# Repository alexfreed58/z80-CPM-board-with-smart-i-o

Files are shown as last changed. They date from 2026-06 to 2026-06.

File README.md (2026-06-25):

# z80-CPM-board-with-smart-I/O
<p>This is yet another retro computer running CPM on an actual Z80 CPU with a twist. Instead of using a traditional UART for communications, it uses a RPi pico module that is no bigger and no more expensive than a UART. But it can do a whole lot more. On this board it also generates the CPU clock that can be set to any desired frequency. If you have a 20 MHz Z80, use 20 MHz.</p>
<p>
There is also a provision to add an ESP32 module that allows connecting to the board via WiFi (telnet server) or BlueTooth. Of course you need to load a simple program onto the ESP32 from the ESP32 examples with some  modifications. Arduino works well.</p>
<p>
I use an SD card for disk emulation. I made a lot of design choices to be somewhat compatible with John Winans' z80-retro computer: "disk" geometry and memory management in particular. However my SD interface is quite different. Instead of bit-banging SPI, I use a couple of TTL (or CMOS) chips. The heart of the interface is a 74(LS/HC)299 universal shift register and some glue logic. I have decided to use several off-the-shelf chips rather than  a single CPLD because if anybody decides to use my design, it will be a lot easier if you don't have much experience with programmable logic. As a result the SPI interface runs at the full CPU clock speed  and to transmit and receive a byte via SPI you only need to write one byte to an i/o port and read a byte back.</p> 
<p>
The board design is done with the (fantastic!) open source Kicad. Likely much less than perfect as it is my first Licad project ever. I used mostly Altium Designer for professional work, but since Kicad is free, anyone can modify and improve the board.</p>

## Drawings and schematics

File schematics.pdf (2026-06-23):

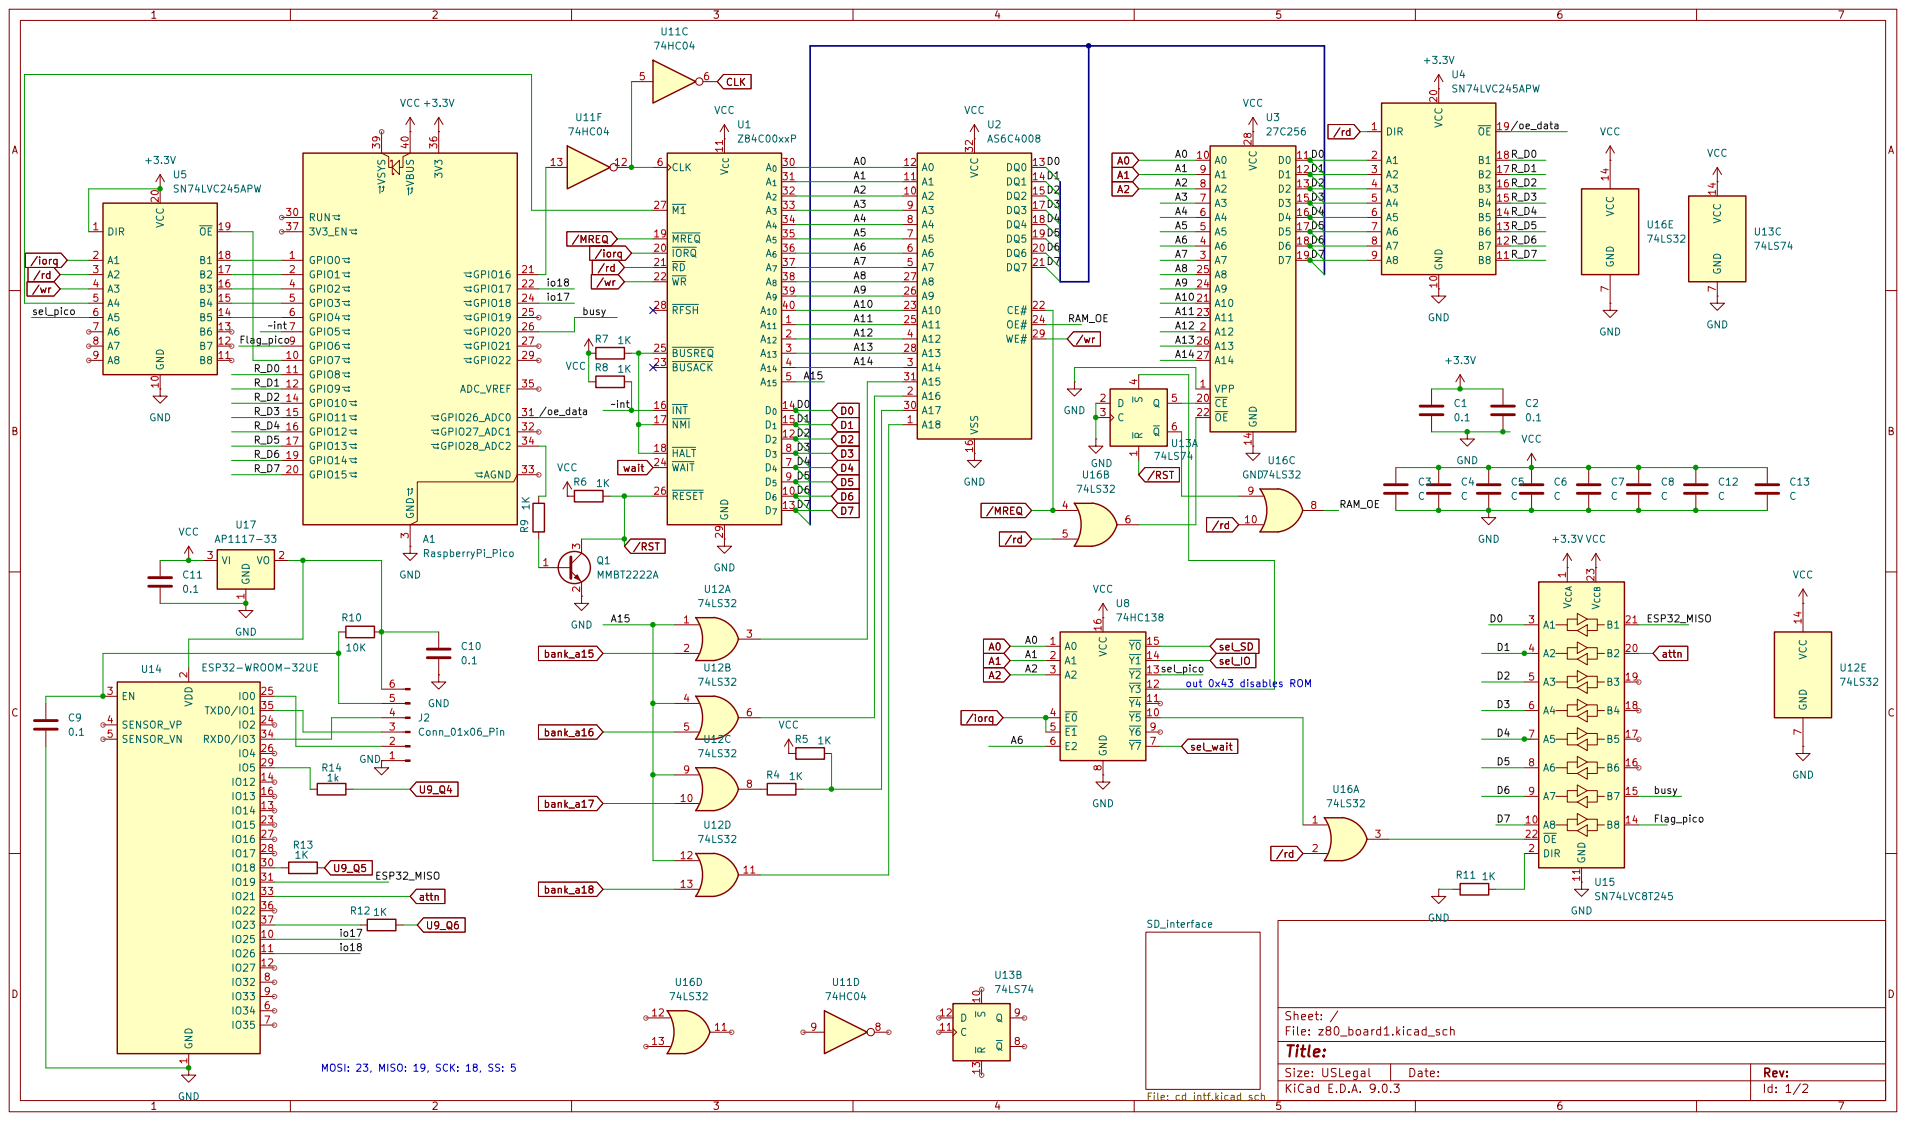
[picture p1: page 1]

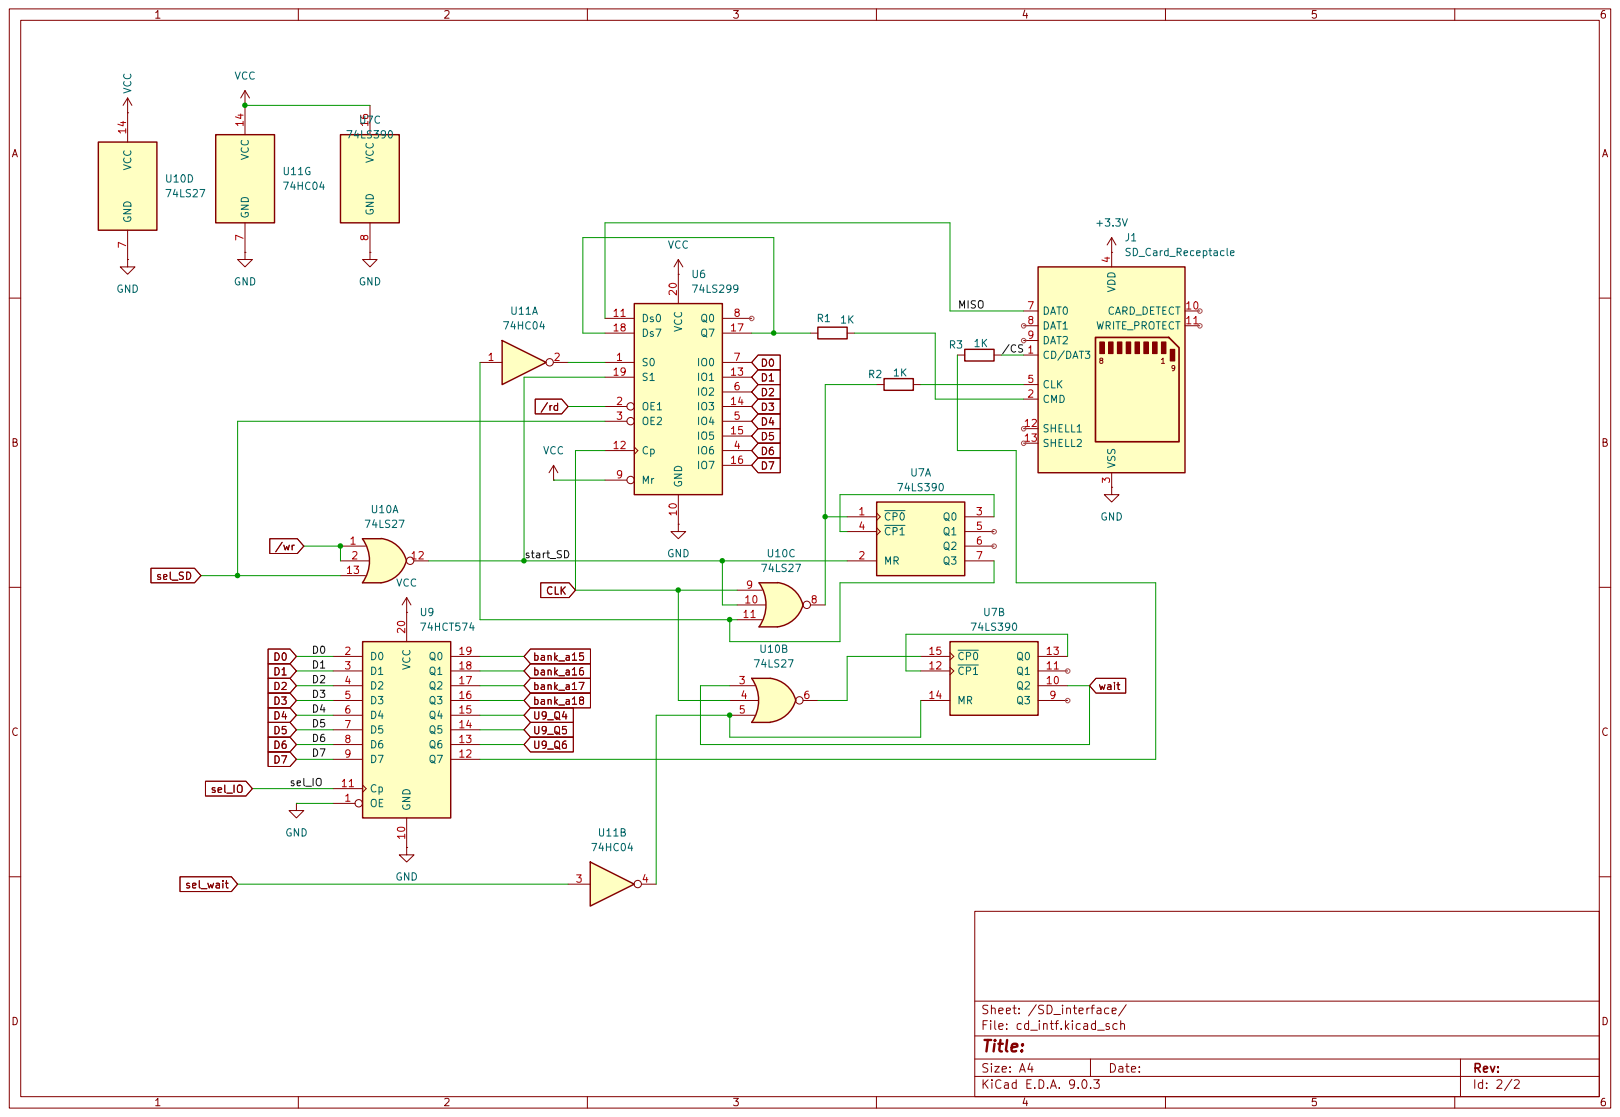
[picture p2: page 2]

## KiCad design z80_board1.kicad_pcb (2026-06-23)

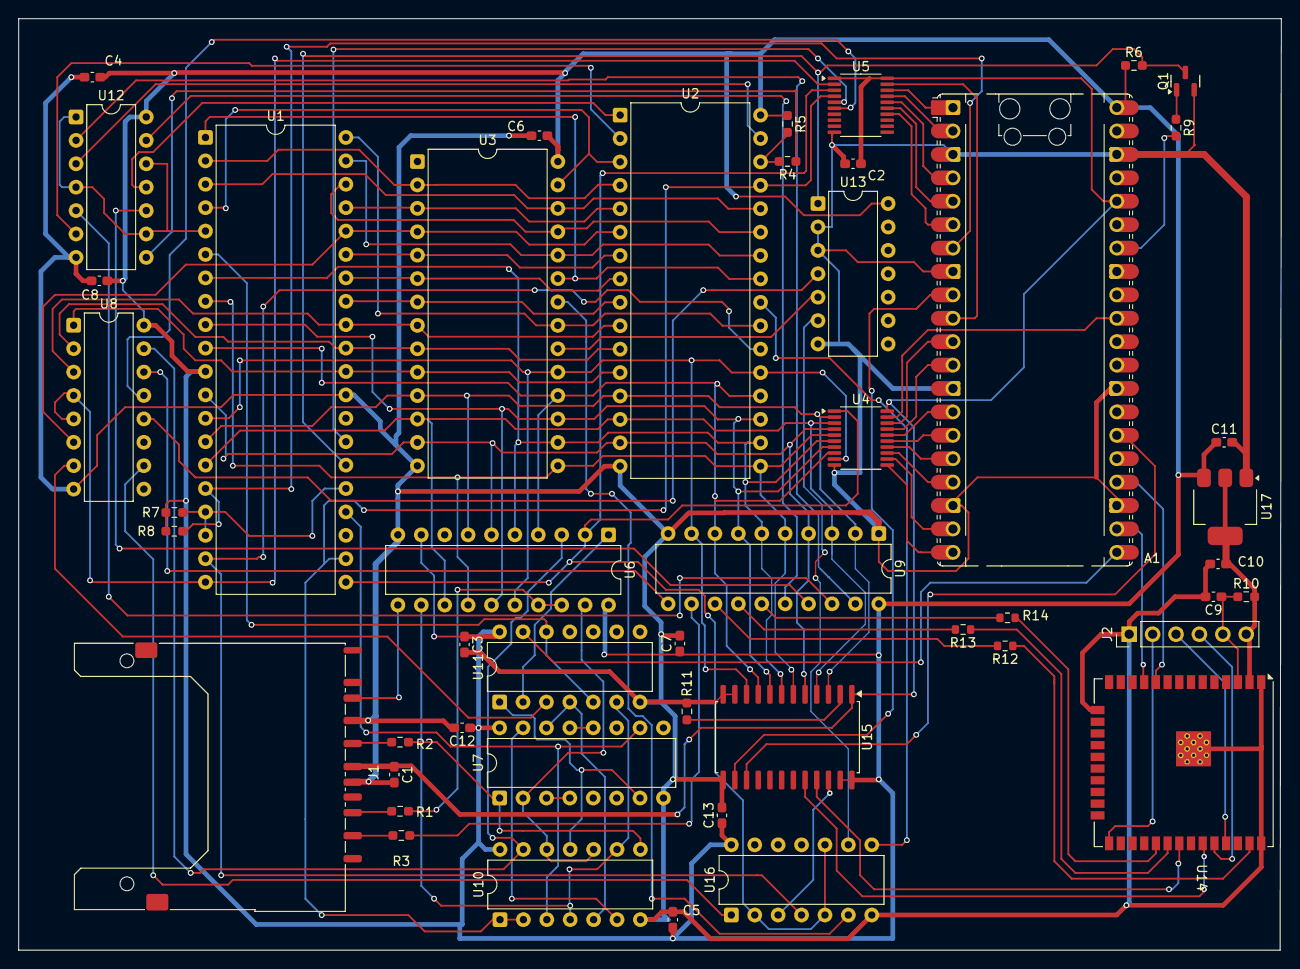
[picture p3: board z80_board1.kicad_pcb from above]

Board: 2 copper layers, 137.0 x 101.1 mm, 48 parts (0 on the bottom side), 108 nets.

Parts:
A1: RaspberryPi_Pico; RaspberryPi_Pico_Common_Unspecified
C1, C2, C9, C10, C11: 0.1; C_0603_1608Metric_Pad1.08x0.95mm_HandSolder
C3, C4, C5, C6, C7, C8, C12, C13: C; C_0603_1608Metric_Pad1.08x0.95mm_HandSolder
J1: SD_Card_Receptacle; SD_Kyocera_145638009511859+
J2: Conn_01x06_Pin; PinHeader_1x06_P2.54mm_Vertical
Q1: MMBT2222A; SOT-23
R1, R2, R3, R4, R5, R6, R7, R8, R9, R11: 1K; R_0603_1608Metric_Pad0.98x0.95mm_HandSolder
R10: 10K; R_0603_1608Metric_Pad0.98x0.95mm_HandSolder
R12, R13: 1K; R_0603_1608Metric
R14: 1k; R_0603_1608Metric
U1: Z84C00xxP; DIP-40_W15.24mm
U2: AS6C4008; DIP-32_W15.24mm
U3: 27C256; DIP-28_W15.24mm
U4, U5: SN74LVC245APW; TSSOP-20_4.4x6.5mm_P0.65mm
U6: 74LS299; DIP-20_W7.62mm
U7: 74LS390; DIP-16_W7.62mm
U8: 74HC138; DIP-16_W7.62mm
U9: 74HCT574; DIP-20_W7.62mm
U10: 74LS27; DIP-14_W7.62mm
U11: 74HC04; DIP-14_W7.62mm
U12, U16: 74LS32; DIP-14_W7.62mm
U13: 74LS74; DIP-14_W7.62mm
U14: ESP32-WROOM-32UE
U15: SN74LVC8T245; SOIC-24W_7.5x15.4mm_P1.27mm
U17: AP1117-33; SOT-223-3_TabPin2

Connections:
+3.3V: A1.36 (3V3), C1.1, C2.1, J1.4 (VDD), U4.20 (VCC), U5.1 (DIR), U5.20 (VCC), U15.1 (V_{CCA})
/A3: U1.33 (A_{3}), U2.9 (A3), U3.7 (A3)
/A4: U1.34 (A_{4}), U2.8 (A4), U3.6 (A4)
/A5: U1.35 (A_{5}), U2.7 (A5), U3.5 (A5)
/A6: U1.36 (A_{6}), U2.6 (A6), U3.4 (A6), U8.6 (E2)
/A7: U1.37 (A_{7}), U2.5 (A7), U3.3 (A7)
/A8: U1.38 (A_{8}), U2.27 (A8), U3.25 (A8)
/A9: U1.39 (A_{9}), U2.26 (A9), U3.24 (A9)
/A10: U1.40 (A_{10}), U2.23 (A10), U3.21 (A10)
/A11: U1.1 (A_{11}), U2.25 (A11), U3.23 (A11)
/A12: U1.2 (A_{12}), U2.4 (A12), U3.2 (A12)
/A13: U1.3 (A_{13}), U2.28 (A13), U3.26 (A13)
/A14: U1.4 (A_{14}), U2.3 (A14), U3.27 (A14)
/A15: U1.5 (A_{15}), U12.1, U12.4, U12.9, U12.12
/ESP32_MISO: U14.31 (IO19), U15.21 (B1)
/Flag_pico: A1.9 (GPIO6), U15.14 (B8)
/RAM_OE: U2.24 (OE#), U16.8
/R_D0: A1.11 (GPIO8), U4.18 (B1)
/R_D1: A1.12 (GPIO9), U4.17 (B2)
/R_D2: A1.14 (GPIO10), U4.16 (B3)
/R_D3: A1.15 (GPIO11), U4.15 (B4)
/R_D4: A1.16 (GPIO12), U4.14 (B5)
/R_D5: A1.17 (GPIO13), U4.13 (B6)
/R_D6: A1.19 (GPIO14), U4.12 (B7)
/R_D7: A1.20 (GPIO15), U4.11 (B8)
/SD_interface/MISO: J1.7 (DAT0), U6.11 (Ds0)
/SD_interface/start_SD: U6.19 (S1), U7.2 (MR), U10.10, U10.12
/SD_interface//CS: J1.1 (CD/DAT3), R3.1
/busy: A1.26 (GPIO20), U15.15 (B7)
/io17: A1.24 (GPIO18), U14.10 (IO25)
/io18: A1.22 (GPIO17), U14.11 (IO26)
/sel_pico: U5.6 (A5), U8.13 (~Y2)
//oe_data: A1.31 (GPIO26_ADC0), U4.19 (~OE)
/~int: A1.7 (GPIO5), R8.2, U1.16 (~INT)
A0: U1.30 (A_{0}), U2.12 (A0), U3.10 (A0), U8.1 (A0)
A1: U1.31 (A_{1}), U2.11 (A1), U3.9 (A1), U8.2 (A1)
A2: U1.32 (A_{2}), U2.10 (A2), U3.8 (A2), U8.3 (A2)
CLK: U6.12 (Cp), U10.4, U10.9, U11.6
D0: U1.14 (D_{0}), U2.13 (DQ0), U3.11 (D0), U4.2 (A1), U6.7 (IO0), U9.2 (D0), U15.3 (A1)
D1: U1.15 (D_{1}), U2.14 (DQ1), U3.12 (D1), U4.3 (A2), U6.13 (IO1), U9.3 (D1), U15.4 (A2)
D2: U1.12 (D_{2}), U2.15 (DQ2), U3.13 (D2), U4.4 (A3), U6.6 (IO2), U9.4 (D2), U15.5 (A3)
D3: U1.8 (D_{3}), U2.17 (DQ3), U3.15 (D3), U4.5 (A4), U6.14 (IO3), U9.5 (D3), U15.6 (A4)
D4: U1.7 (D_{4}), U2.18 (DQ4), U3.16 (D4), U4.6 (A5), U6.5 (IO4), U9.6 (D4), U15.7 (A5)
D5: U1.9 (D_{5}), U2.19 (DQ5), U3.17 (D5), U4.7 (A6), U6.15 (IO5), U9.7 (D5), U15.8 (A6)
D6: U1.10 (D_{6}), U2.20 (DQ6), U3.18 (D6), U4.8 (A7), U6.4 (IO6), U9.8 (D6), U15.9 (A7)
D7: U1.13 (D_{7}), U2.21 (DQ7), U3.19 (D7), U4.9 (A8), U6.16 (IO7), U9.9 (D7), U15.10 (A8)
GND: A1.3 (GND), A1.8 (GND), A1.13 (GND), A1.18 (GND), A1.23 (GND), A1.28 (GND), A1.38 (GND), C1.2, C2.2, C3.2, C4.2, C5.2, C6.2, C7.2, C8.2, C9.2, C10.2, C11.2, C12.2, C13.2, J1.3 (VSS), J1.6 (VSS), J2.1, Q1.2 (E), R11.1, U1.29 (GND), U2.16 (VSS), U3.1 (VPP), U3.14 (GND), U4.10 (GND), U5.10 (GND), U6.10 (GND), U7.8 (GND), U8.8 (GND), U9.1 (OE), U9.10 (GND), U10.7 (GND), U11.7 (GND), U12.7 (GND), U13.2 (D), U13.3 (C), U13.7 (GND), U14.1 (GND), U14.15 (GND), U14.38 (GND), U14.39 (GND), U15.11 (GND), U15.12 (GND), U15.13 (GND), U16.7 (GND), U17.1 (GND)
unnamed: A1.1 (GPIO0), U5.18 (B1)
unnamed: A1.2 (GPIO1), U5.17 (B2)
unnamed: A1.4 (GPIO2), U5.16 (B3)
unnamed: A1.5 (GPIO3), U5.15 (B4)
unnamed: A1.6 (GPIO4), U5.14 (B5)
unnamed: A1.10 (GPIO7), U5.19 (~OE)
unnamed: A1.21 (GPIO16), U11.13
unnamed: A1.34 (GPIO28_ADC2), R9.2
unnamed: J1.5 (CLK), R2.2
unnamed: J1.2 (CMD), R1.2
unnamed: J2.2, U14.25 (IO0)
unnamed: J2.3, U14.35 (TXD0/IO1)
unnamed: J2.4, U14.34 (RXD0/IO3)
unnamed: C9.1, J2.5, R10.1, U14.3 (EN)
unnamed: C10.1, J2.6, R10.2, U14.2 (VDD), U17.2 (VO)
unnamed: Q1.1 (B), R9.1
unnamed: R4.1, U12.8
unnamed: U1.6 (CLK), U11.5, U11.12
unnamed: R7.2, U1.17 (~NMI), U1.18 (~HALT), U1.25 (~BUSREQ)
unnamed: U1.27 (~M1), U5.5 (A4)
unnamed: U2.31 (A15), U12.3
unnamed: U2.2 (A16), U12.6
unnamed: R4.2, R5.2, U2.30 (A17)
unnamed: U2.1 (A18), U12.11
unnamed: U3.22 (~OE), U16.6
unnamed: R1.1, U6.17 (Q7), U6.18 (Ds7)
unnamed: U6.1 (S0), U11.2
unnamed: U7.3 (Q0), U7.4 (~CP1)
unnamed: U7.7 (Q3), U10.11, U11.1
unnamed: R2.1, U7.1 (~CP0), U10.8
unnamed: U7.14 (MR), U10.5, U11.4
unnamed: U7.12 (~CP1), U7.13 (Q0)
unnamed: U7.15 (~CP0), U10.6
unnamed: U8.10 (~Y5), U16.1
unnamed: R3.2, U9.12 (Q7)
unnamed: U3.20 (~CE), U13.5 (Q)
unnamed: U13.6 (~Q), U16.9
unnamed: U8.12 (~Y3), U13.4 (~S)
unnamed: R14.1, U14.29 (IO5)
unnamed: R13.1, U14.30 (IO18)
unnamed: R12.1, U14.37 (IO23)
unnamed: R11.2, U15.2 (DIR)
unnamed: U15.22 (~OE), U16.3
U9_Q4: R14.2, U9.15 (Q4)
U9_Q5: R13.2, U9.14 (Q5)
U9_Q6: R12.2, U9.13 (Q6)
VCC: A1.40 (VBUS), C3.1, C4.1, C5.1, C6.1, C7.1, C8.1, C11.1, C12.1, C13.1, R5.1, R6.1, R7.1, R8.1, U1.11 (V_{CC}), U2.32 (VCC), U3.28 (VCC), U6.9 (Mr), U6.20 (VCC), U7.16 (VCC), U8.16 (VCC), U9.20 (VCC), U10.14 (VCC), U11.14 (VCC), U12.14 (VCC), U13.14 (VCC), U15.23 (V_{CCB}), U15.24 (V_{CCB}), U16.14 (VCC), U17.3 (VI)
attn: U14.33 (IO21), U15.20 (B2)
bank_a15: U9.19 (Q0), U12.2
bank_a16: U9.18 (Q1), U12.5
bank_a17: U9.17 (Q2), U12.10
bank_a18: U9.16 (Q3), U12.13
sel_IO: U8.14 (~Y1), U9.11 (Cp)
sel_SD: U6.3 (OE2), U8.15 (~Y0), U10.13
sel_wait: U8.7 (~Y7), U11.3
wait: U1.24 (~WAIT), U7.10 (Q2), U10.3
/MREQ: U1.19 (~MREQ), U2.22 (CE#), U16.4
/RST: Q1.3 (C), R6.2, U1.26 (~RESET), U13.1 (~R)
/iorq: U1.20 (~IORQ), U5.2 (A1), U8.4 (~E0), U8.5 (~E1)
/rd: U1.21 (~RD), U4.1 (DIR), U5.3 (A2), U6.2 (OE1), U16.2, U16.5, U16.10
/wr: U1.22 (~WR), U2.29 (WE#), U5.4 (A3), U10.1, U10.2
